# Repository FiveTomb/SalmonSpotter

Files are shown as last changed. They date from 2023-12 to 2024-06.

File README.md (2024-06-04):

# SalmonSpotter

## Project Overview
**Primary Goal:**  
The SalmonSpotter project aims to build a durable device capable of withstanding the harsh weather conditions of an Alaskan lake. It collects data to identify prime areas for salmon spawning, ensuring battery efficiency, wireless data transmission, and cost-effectiveness.

**Problem Solved:**  
The device gathers data to help scientists understand why salmon choose specific spawning areas.

## Features
- **Sensors:** TDS, IMU, pH, water and air temperature sensors.
- **Data Transmission:** Uses Zolertia RE-Mote to send data wirelessly (802.15.4) to a land-based node.
- **Modularity:** Sensors are connected via a custom daughter-board on an I2C bus for easy replacement.

## Installation Instructions
### Prerequisites
- Set up a cross-compile toolchain for compiling the application for both transmitting and receiving nodes.

*Step-by-step guide to be added later.*

## Usage
*Detailed usage instructions to be added later.*

**Commands:** No specific commands required to use the system.

## Architecture
### Hardware
#### Sensors:
1. **SHT31 Temperature & Humidity Sensor (-40℃~125℃) - I2C**  
   - **Price:** $8.49
2. **Soil Digital Temperature & Humidity Sensor Probe**  
   - **Description:** Waterproof, Stainless Steel Case Housing, High Accuracy, Low Consumption, I2C Output  
   - **Price:** $15.46
3. **LSM6DSO**  
   - **Price:** $12.95
4. **Atlas Scientific Gravity Analog pH Kit**  
   - **Price:** $67.99
5. **CQRobot Ocean: TDS (Total Dissolved Solids)**  
   - **Price:** $11.90

**Total Cost:** $116.79

#### Zolertia RE-Mote Specifications:
- **MCU:** CC2538 (ARM Cortex-M3 with on-board 2.4GHz radio)
- **Radio:**
  - Two radio interfaces (IEEE 802.15.4): 2.4GHz and 863-950MHz
  - RP-SMA connector for external antenna (with a RF switch to select either 2.4GHz/Sub-GHz radio)
- **USB-to-Serial:** CP2104
- **Peripherals:** RTCC, built-in battery charger for LiPo batteries, External WDT (optional), Micro-SD
- **Others:** RGB LED, power management block (150nA when the mote is shutdown)

### Software
- **Operating System:** Contiki-NG (open source with extensive documentation)
- **Schematic Diagrams:** Included in the KiCad project folder in the repository.

## Contributors
- Alexander Regueiro
- Brian Neris
- Daniel Izquierdo

## Contact
- **Alexander Regueiro:** [alexinquiries1020@proton.me](mailto:alexinquiries1020@proton.me)

## License
- GNU License

## Demo
*Videos and pictures to be added later.*

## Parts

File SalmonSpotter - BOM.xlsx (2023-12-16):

Sensor | Price
SHT31 Temperature & Humidity Sensor (-40℃~125℃) - I2C (https://www.amazon.com/HiLetgo-Temperature-Humidity-Interface-GY-SHT31-D/dp/B07ZSZW92J) | $8.49
Soil Digital Temperature & Humidity Sensor Probe Waterproof Stainless Steel Case Housing High Accuracy Low Consumption I2C Output Practice DIY(SHT31) (https://www.amazon.com/Temperature-Humidity-Waterproof-Stainless-Consumption/dp/B07X8P5F5Z) | $15.46
LSM6DSO (https://www.digikey.com/en/products/detail/sparkfun-electronics/SEN-18020/14313960) | $12.95
Atlas Scientific Gravity Analog pH Kit (https://atlas-scientific.com/kits/gravity-analog-ph-kit/) | $67.99
CQRobot Ocean: TDS (Total Dissolved Solids) (https://www.amazon.com/CQRobot-Ocean-Compatible-Scientific-Laboratory/dp/B08KXRHK7H) | $11.90
Total | $116.79

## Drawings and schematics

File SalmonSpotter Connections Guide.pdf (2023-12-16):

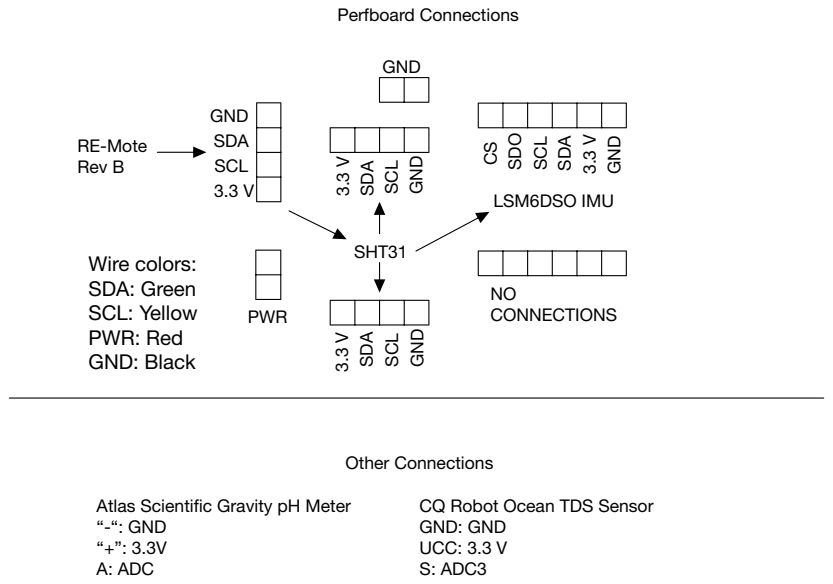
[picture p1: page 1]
SDA; SCL; GND; SHT31; RE-Mote Rev B; NO CONNECTIONS; Perfboard Connections; Wire colors: SDA: Green SCL: Yellow PWR: Red GND: Black; Other Connections; PWR

LSM6DSO IMU SDO SCL SDA 3.3 V CS

Atlas Scientific Gravity pH Meter
“-“: GND
A: ADC

CQ Robot Ocean TDS Sensor
GND: GND
UCC: 3.3 V
S: ADC3

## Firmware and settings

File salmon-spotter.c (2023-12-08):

#include "contiki.h"
#include "adc-zoul.h"
#include "dev/i2c.h"
#include "dev/gpio-hal.h"
#include "dev/leds.h"
#include "dev/serial-line.h"
#include "lib/sensors.h"
#include "net/routing/routing.h"
#include "random.h"
#include "net/netstack.h"
#include "net/ipv6/simple-udp.h"
#include <stdio.h>
#include <stdint.h>
#include <inttypes.h>
#include "sys/log.h"

#define LOG_MODULE "App"
#define LOG_LEVEL LOG_LEVEL_INFO

#define WITH_SERVER_REPLY  1
#define UDP_CLIENT_PORT	8765
#define UDP_SERVER_PORT	5678

#define SEND_INTERVAL		  (5 * CLOCK_SECOND)

static struct simple_udp_connection udp_conn;
static uint32_t rx_count = 0;

// Scaling factor for fixed-point arithmetic
#define SCALE_FACTOR_PH 10000
#define SCALE_FACTOR_TDS 1000

// SHT31 Sensors (Temp)
#define SHT_31_DFLT_ADDR 0x44
#define SHT_31_ALT_ADDR 0x45
#define SHT31_READ_TEMP_HUM 0x2400

// Hold raw values from SHT31
static uint16_t temperature, outside_temperature;
static uint16_t pH_value;
static uint16_t tds_value_ppm;

// Hold converted values for SHT31
int16_t temperature_celsius_x100, outside_temperature_x100;

// Gravity pH Sensor
#define ADC_MAX_PH_SENSOR 2047
#define VREF_PH_SENSOR 3300    // Reference voltage in millivolts
#define ADC_RESOLUTION_PH_SENSOR (VREF_PH_SENSOR / ADC_MAX_PH_SENSOR)

// CQRobot TDS Sensor
#define VREF_TDS_SENSOR 3300 // Reference voltage in milliwatts
#define SCOUNT 30
#define TEMP_COEF 20
#define STANDARD_TEMP_TDS 25000

// LSM6DSO Addresses
#define LSM6DSO_DFLT_ADDR 0x6B
#define LSM6DSO_ALT_ADDR 0x6A

// LSM6DSO Registers
#define LSM6DSO_CTRL1_XL 0x10 // Config regoster for accelerometer
#define LSM6DSO_CTRL2_G 0x11  // Config register for gyroscope
#define LSM6DSO_OUTX_L_G 0x22 
#define LSM6DSO_OUTX_H_G 0x23
#define LSM6DSO_OUTY_L_G 0X24
#define LSM6DSO_OUTY_H_G 0X25
#define LSM6DSO_OUTZ_L_G 0X26
#define LSM6DSO_OUTZ_H_G 0X27
#define LSM6DSO_OUTX_L_A 0x28
#define LSM6DSO_OUTX_H_A 0x29
#define LSM6DSO_OUTY_L_A 0x2A
#define LSM6DSO_OUTY_H_A 0x2B
#define LSM6DSO_OUTZ_L_A 0x2C
#define LSM6DSO_OUTZ_H_A 0x2D
#define LSM6DSO_WHO_AM_I 0x0F // Register with pre defined value, good for testing signal to IMU

// Variables to hold information from axes
uint16_t accel_x, accel_y, accel_z, gyro_x, gyro_y, gyro_z;

// Initializing LSM6DSO IMU accelerometer and gyroscope
void initLSM6DSO()
{
  uint8_t config_byte = 0x48; // Example configuration byte for gyroscope and accelerometer
  uint8_t buffer[3];
  // Init LSM6DSO
  // Configure Accelerometer
  buffer[0] = LSM6DSO_CTRL1_XL;
  buffer[1] = config_byte;
  // Write to CTRL1_XL to configure the accelerometer
  i2c_burst_send(LSM6DSO_DFLT_ADDR, buffer, 2);

  // Configure Gyroscope
  buffer[0] = LSM6DSO_CTRL2_G;
  buffer[1] = config_byte;
  // Write to CTRL1_XL to configure the gyroscope
  i2c_burst_send(LSM6DSO_DFLT_ADDR, buffer, 2);
}

// Read a register from the LSM6DSO IMU
int16_t readSensorData(uint8_t sensorAddress, uint8_t registerAddress)
{
    uint8_t buffer[3];
    uint16_t combinedData;
    // Reading data
    buffer[0] = registerAddress; // Set the register address to start reading
    i2c_burst_send(sensorAddress, buffer, 1); // Send register address
    i2c_burst_receive(sensorAddress, buffer, 2); // Read 2 bytes

    combinedData = (int16_t)((buffer[1] << 8) | buffer[0]);

    return combinedData;
}

// Temperature conversion using fixed-point arithmetic
int16_t raw_to_celsius_x100(uint16_t raw_temp) {
    int32_t temp = (17500 * raw_temp) >> 16; // Multiplying by 100 to keep 2 decimal places
    return (int16_t)temp - 4500; // Subtracting 4500 (which is -45.00 in this fixed-point representation)
}

// Humidity conversion using fixed point arithmetic
int16_t raw_to_humidity_x100(uint16_t raw_humidity) {
    int32_t hum = (10000 * raw_humidity) >> 16; // Multiplying by 100 to keep 2 decimal places
    return (int16_t)hum;
}

// Assuming 'voltage' is already an integer representing the voltage in millivolts
int calculateTDS(int voltage, int temperature) {
    long long v = (long long)voltage; // Promote to long long to prevent overflow

    // Temperature compensation
    long long tempCompensationFactor = SCALE_FACTOR_TDS + TEMP_COEF * (temperature - STANDARD_TEMP_TDS);
    long long compensatedVoltage = (v * SCALE_FACTOR_TDS) / tempCompensationFactor;

    // Scale the constants
    long long const1 = 133420LL; // 133.42 * SCALE_FACTOR_TDS
    long long const2 = 255860LL; // 255.86 * SCALE_FACTOR_TDS
    long long const3 = 857390LL; // 857.39 * SCALE_FACTOR_TDS

    // Calculate TDS
    long long tds = (const1 * compensatedVoltage * compensatedVoltage * compensatedVoltage 
                - const2 * compensatedVoltage * compensatedVoltage 
                + const3 * compensatedVoltage) / (2 * SCALE_FACTOR_TDS * SCALE_FACTOR_TDS * SCALE_FACTOR_TDS);

    return (int)(tds / SCALE_FACTOR_TDS); // Adjust final scale and convert back to int
}

static void
udp_rx_callback(struct simple_udp_connection *c,
         const uip_ipaddr_t *sender_addr,
         uint16_t sender_port,
         const uip_ipaddr_t *receiver_addr,
         uint16_t receiver_port,
         const uint8_t *data,
         uint16_t datalen)
{

  LOG_INFO("Received response '%.*s' from ", datalen, (char *) data);
  LOG_INFO_6ADDR(sender_addr);
#if LLSEC802154_CONF_ENABLED
  LOG_INFO_(" LLSEC LV:%d", uipbuf_get_attr(UIPBUF_ATTR_LLSEC_LEVEL));
#endif
  LOG_INFO_("\n");
  rx_count++;
}

// Networking Processes
PROCESS(udp_client_process, "UDP Client Process");
// Individual Sensor Processes
PROCESS(sht31_process, "Water Temperature readings");
PROCESS(sht31_alt_process, "Outdoor Temperature readings");
PROCESS(ph_sensor_process, "Grvaity pH Sensor");
PROCESS(tds_sensor_process, "TDS Sensor Readings");
PROCESS(lsm6dso_process, "IMU readings");
AUTOSTART_PROCESSES(&sht31_process, &sht31_alt_process, &ph_sensor_process, &tds_sensor_process, &lsm6dso_process, &udp_client_process);
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

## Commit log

2023-12-16 Uploaded connections guide and BOM
    [SalmonSpotter - BOM.xlsx]
2023-12-18 Uploaded KiCad project with Schematic
    [senior-project.kicad_pcb, senior-project.kicad_sch]
2023-12-18 Renamed KiCad project folder
    [senior-project.kicad_pcb, senior-project.kicad_sch]
